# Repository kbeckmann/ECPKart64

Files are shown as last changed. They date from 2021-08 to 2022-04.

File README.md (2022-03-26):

# ECPKart64

A Lattice ECP5 based FPGA Flash Cart for the Nintendo 64

## Build and load over serial

```

# First install FPGA toolchain and LiteX

# Build and load stuff
make bitstream
make load_bitstream
make load_app

# Manually write "reboot" in the terminal, in order to trigger the upload of the app

# Upload a ROM
python -m gateware.ecpkart64.uploader2 --port /dev/ttyUSB1 --csr-csv csr.csv --cic --file myrom.z64

# Turn on power on the N64

```

## SD-Card

Currently this doesn't work properly for some reason (sd-card driver does not manage to interact with the card properly). But these are the steps normally taken:

```
# Build
make bitstream
make app

# Format and mount an SD-Card with FAT
sudo mkfs.vfat -F32 /dev/...
sudo mount /dev/... /mnt/usb

# Mount it and copy files to it
cp build/kilsyth/software/app/app.bin /mnt/usb/
cp rom.z64 /mnt/usb/

# Create boot.json with your configuration
echo '{
	"rom.z64":	0x40000000,
	"app.bin":	0x20000000
}' > /mnt/usb/boot.json

# Unmount, insert and boot. Turn on N64.

```

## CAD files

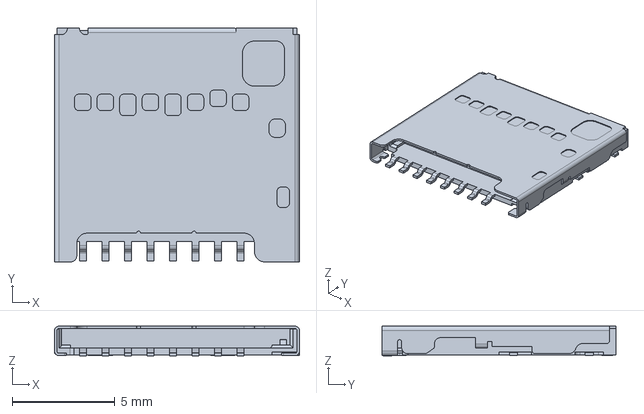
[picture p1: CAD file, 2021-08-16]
hw/3d/1040310811.stp
11.9 x 11.4 x 1.45 mm

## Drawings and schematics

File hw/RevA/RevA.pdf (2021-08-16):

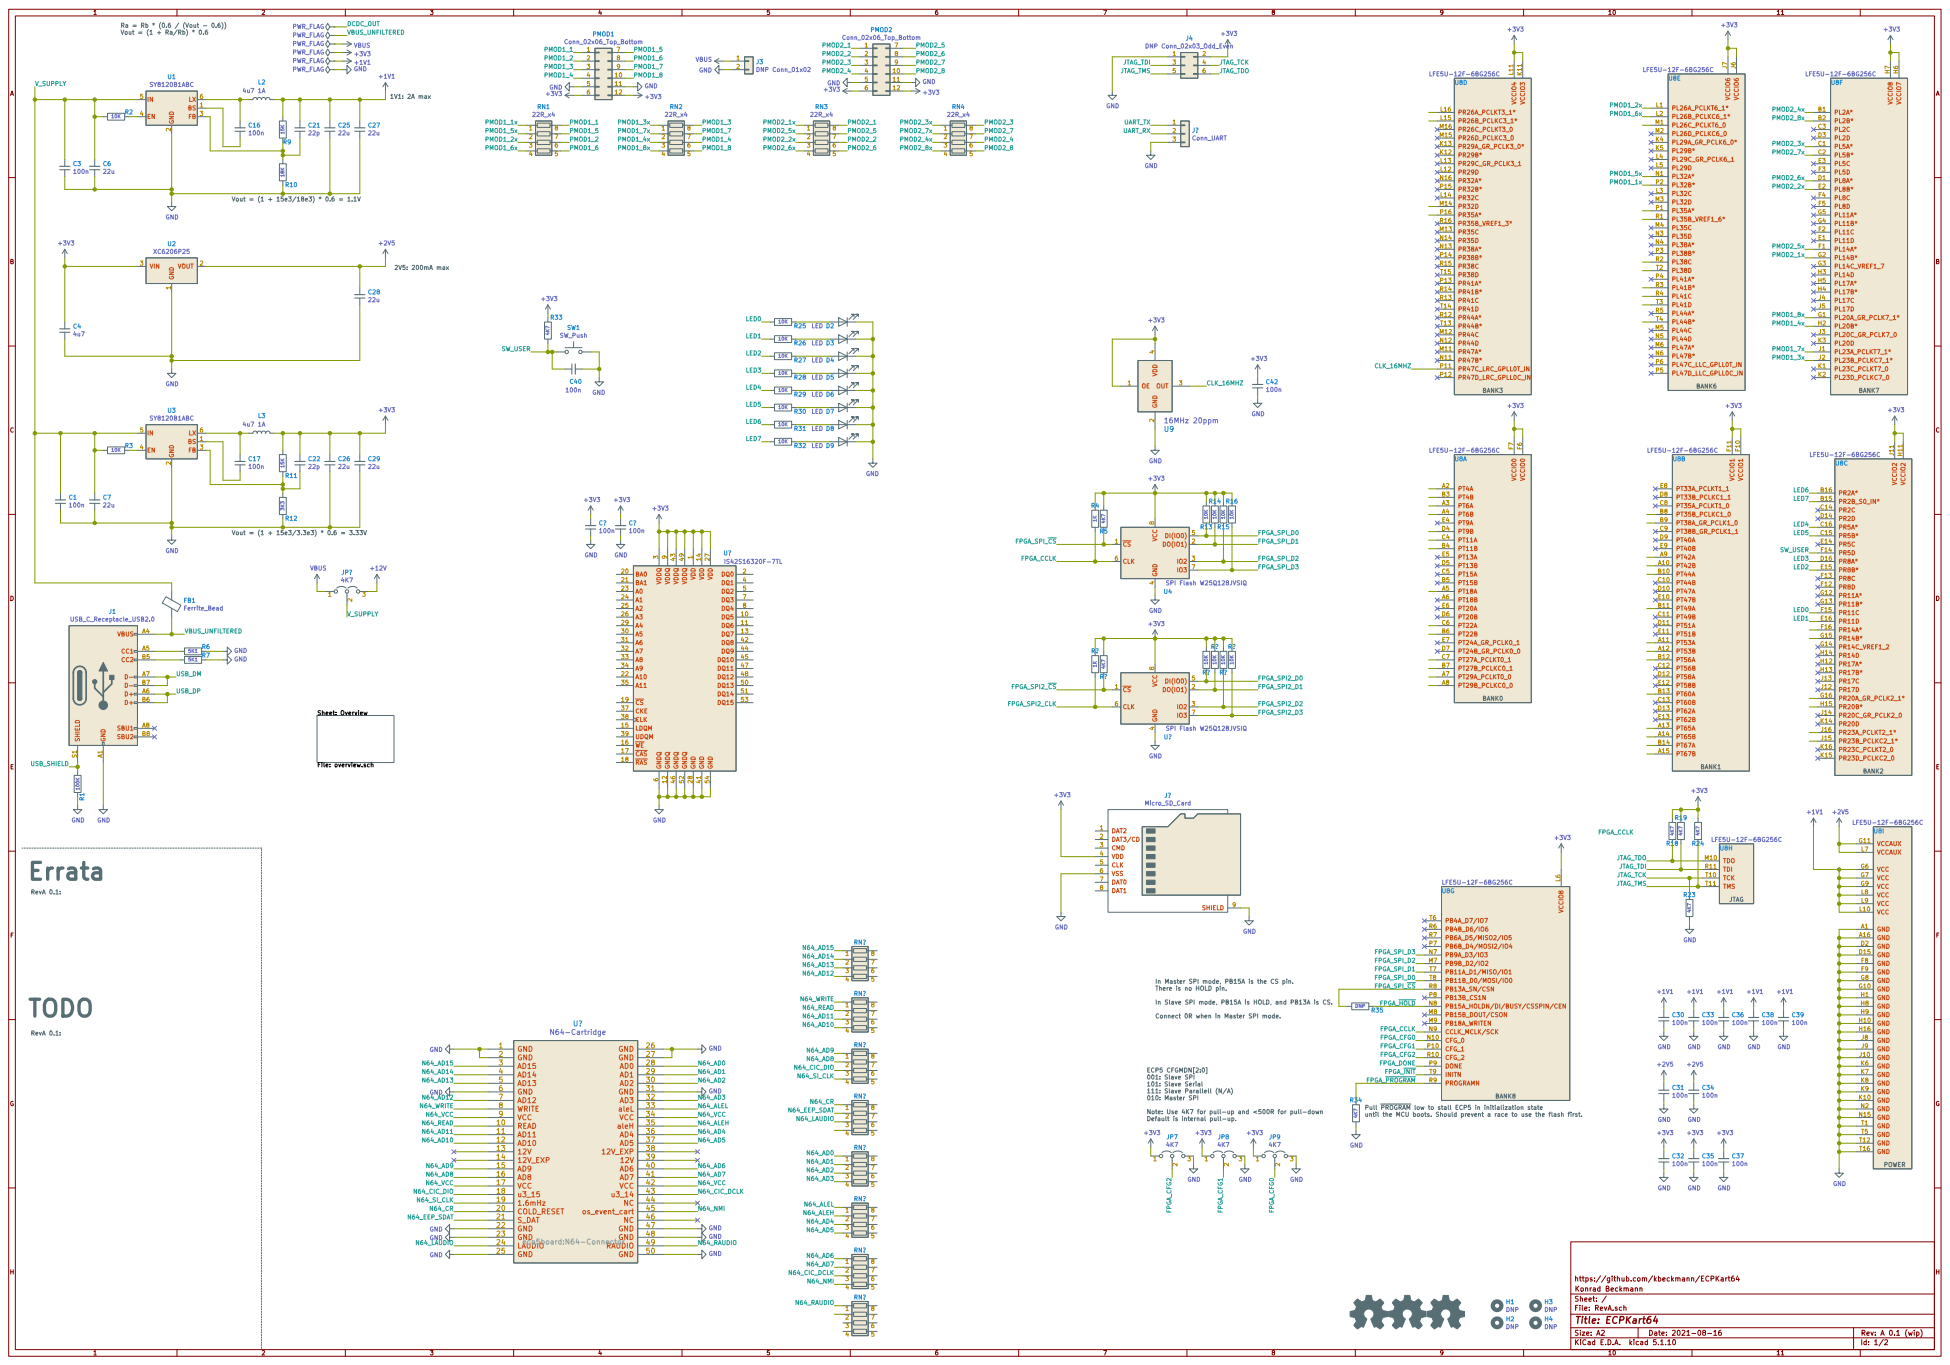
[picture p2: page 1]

3 A5 30 A6 31 A7 32 A8 33 A9 34 A11 35 CKE 37 CLK 38 UDQM 39 DQ1 4 GND 41 DQ8 42 VDDQ 43 DQ9 44 DQ10 45 GNDQ 46 DQ11 47 DQ12 48 VDDQ 49 DQ2 5 DQ13 50 DQ14 51 GNDQ 52 DQ15 53 GND 54 GNDQ

until the MCU boots. Should prevent a race to use the flash first. RevA 0.1:

In Master SPI mode, PB15A is the CS pin.
There is no HOLD pin.

ECP5 CFGMDN[2:0] 001: Slave SPI 101: Slave Serial 111: Slave Parallell (N/A) 010: Master SPI Note: Use 4K7 for pull-up and <500R for pull-down

Default is internal pull-up.

https://github.com/kbeckmann/ECPKart64
File: RevA.sch Sheet: / Konrad Beckmann

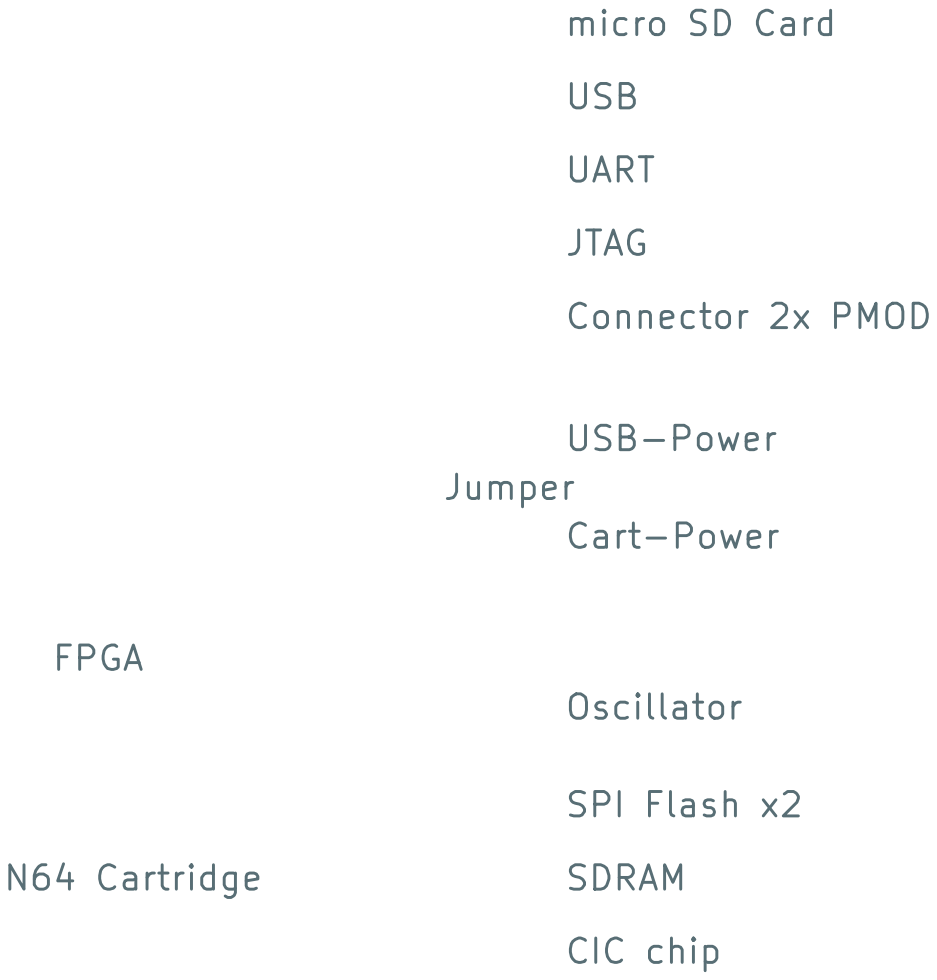
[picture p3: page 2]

SPI Flash x2 USB micro SD Card UART

Cart-Power USB-Power Jumper Oscillator Connector 2x PMOD

Id: 2/2 Title: File: overview.sch Sheet: /Overview/

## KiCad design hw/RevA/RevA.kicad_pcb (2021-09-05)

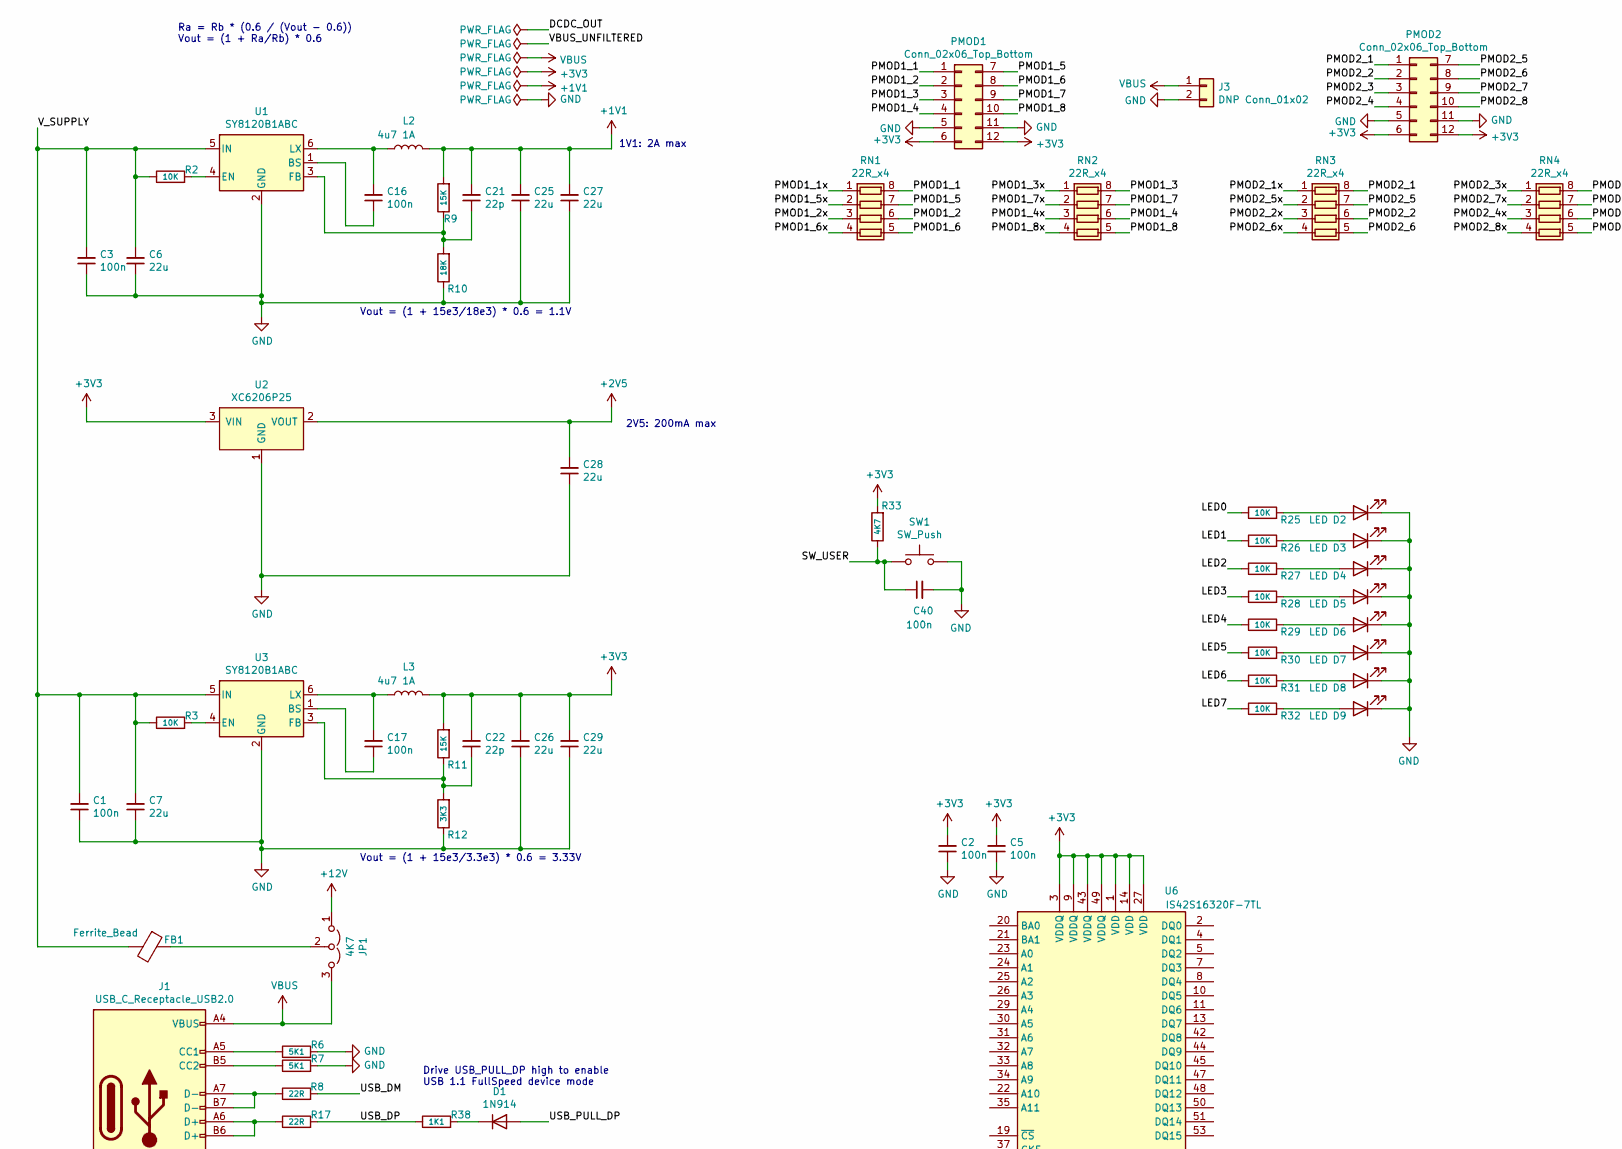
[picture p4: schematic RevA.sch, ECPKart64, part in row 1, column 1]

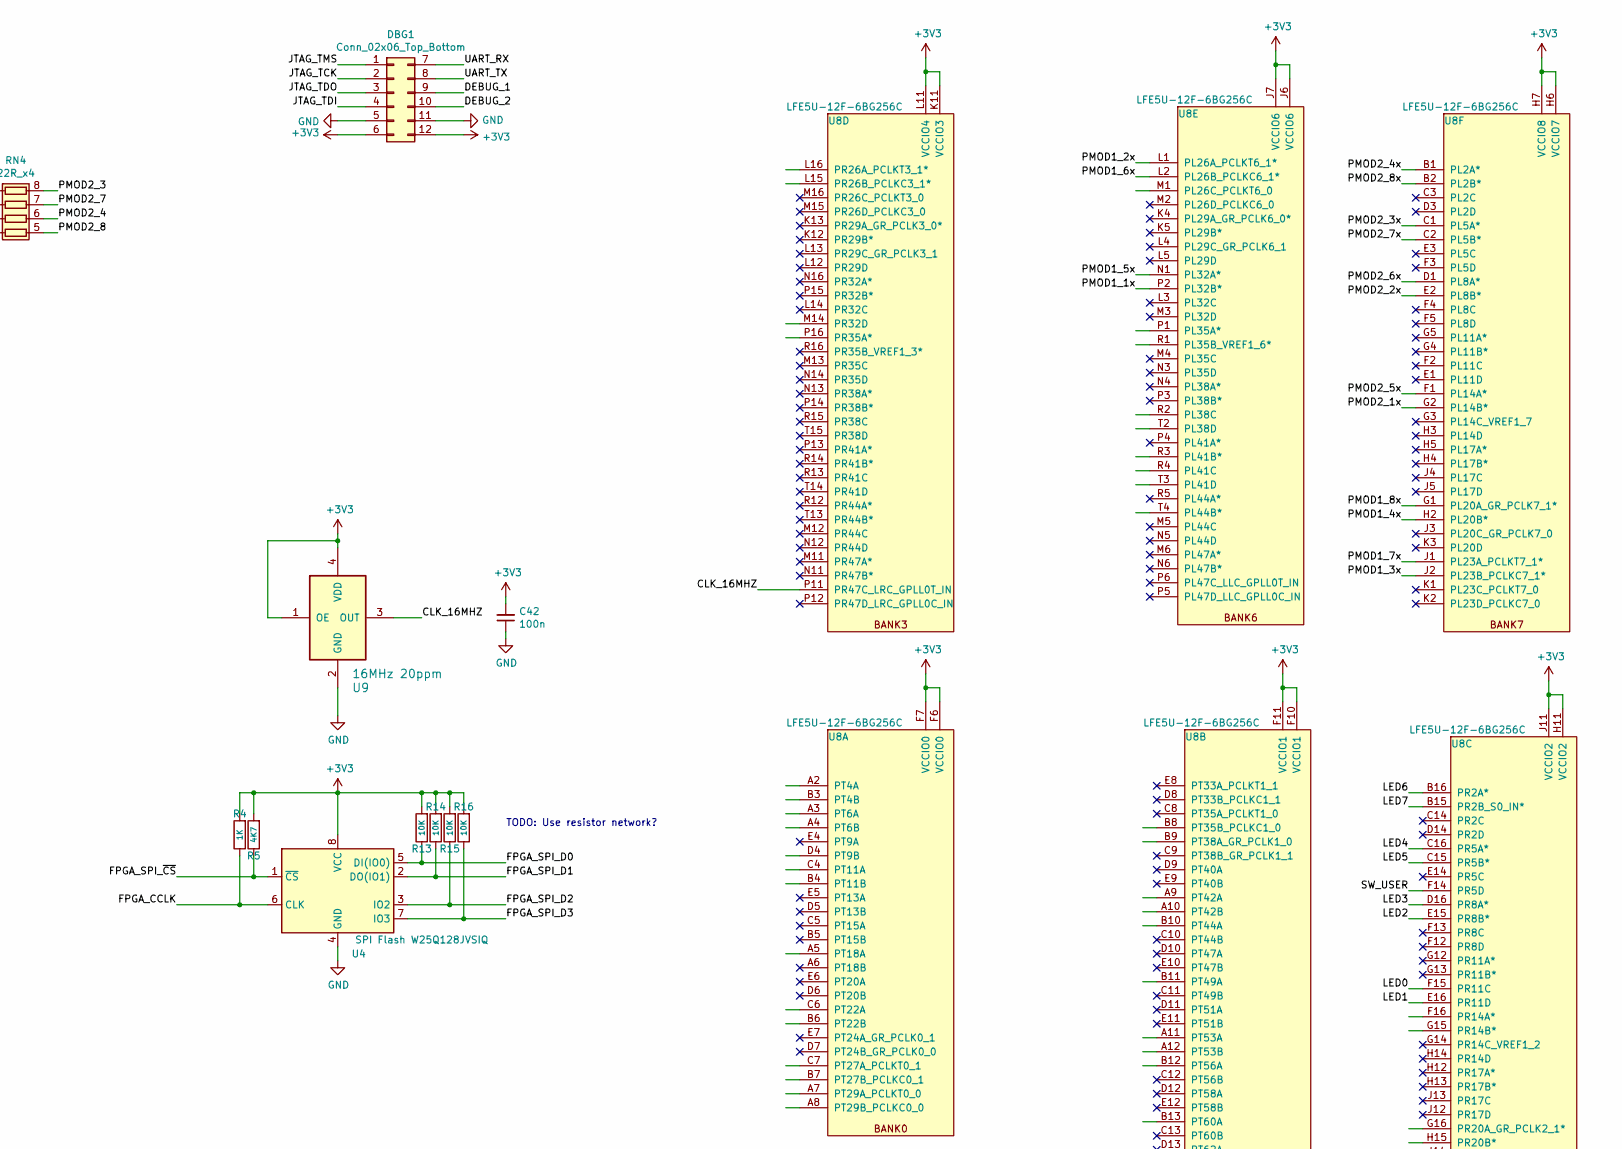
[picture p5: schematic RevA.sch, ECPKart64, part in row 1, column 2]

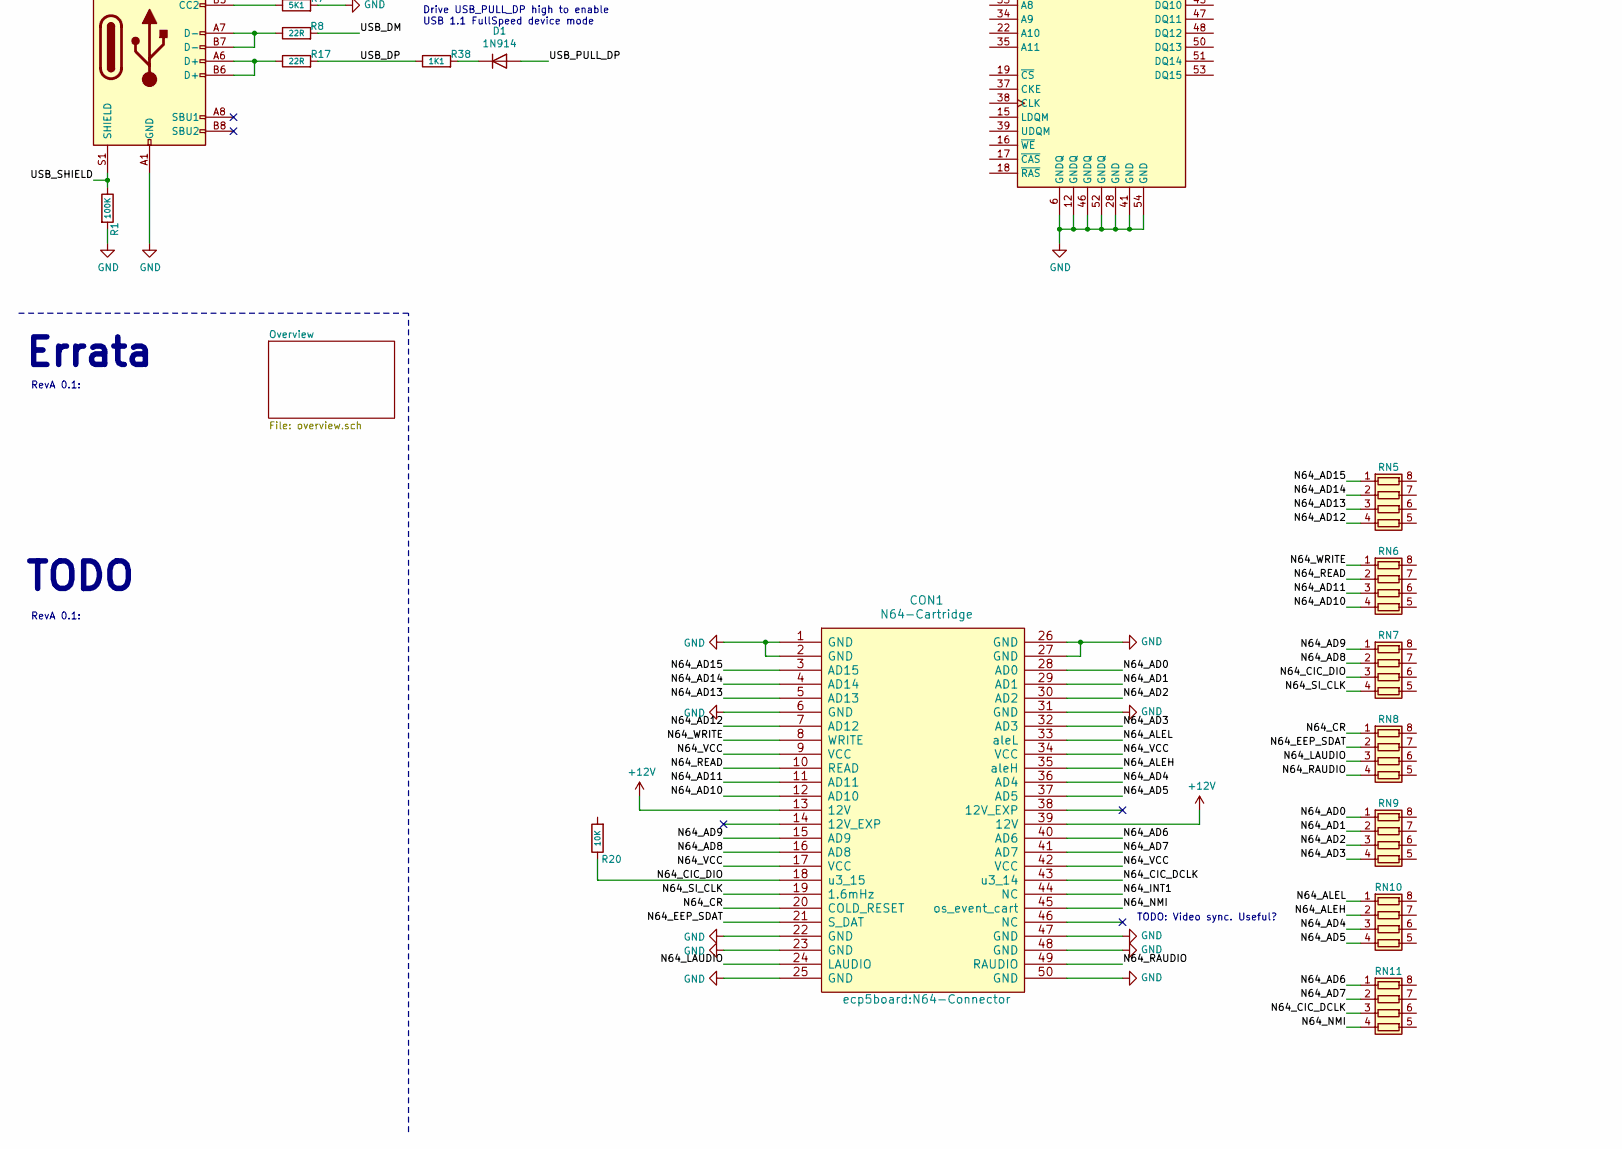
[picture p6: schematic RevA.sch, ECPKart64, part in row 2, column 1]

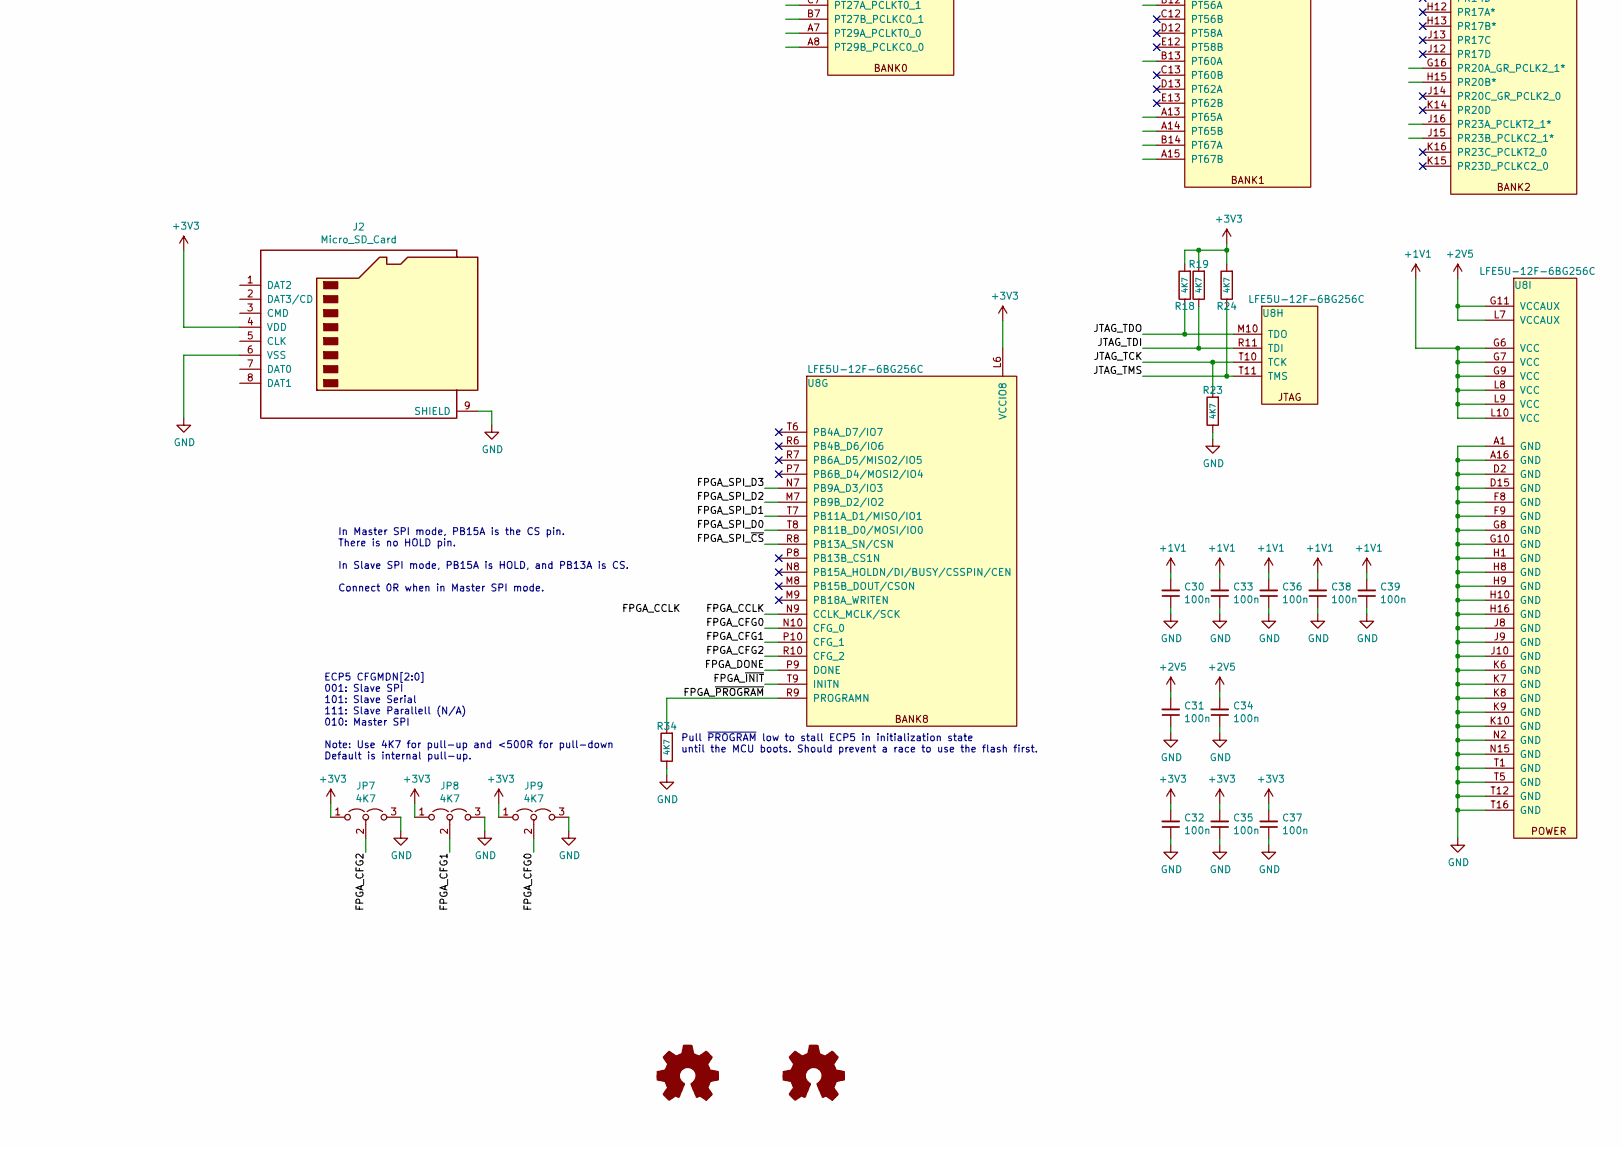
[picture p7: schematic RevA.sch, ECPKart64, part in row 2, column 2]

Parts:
C1, C2, C3, C5, C16, C17, C30, C31, C32, C33, C34, C35, C36, C37, C38, C39, C40, C42: 100n; C_0402_1005Metric
C6, C7, C25, C26, C27, C28, C29: 22u; C_0805_2012Metric; LCSC C98190
C21, C22: 22p; C_0402_1005Metric
CON1: N64-Cartridge; N64-Connector
D1: 1N914; D_SOD-323_HandSoldering
D2, D3, D4, D5, D6, D7, D8, D9: LED; LED_0603_1608Metric; LCSC C84263
DBG1: Conn_02x06_Top_Bottom; PMOD_Socket_2x06_P2.54mm_Horizontal; LCSC C239357
FB1: Ferrite_Bead; L_0805_2012Metric; LCSC C88993
J1: USB_C_Receptacle_USB2.0; USB_C_Receptacle_GT-USB-7010; LCSC C165948
J2: Micro_SD_Card; microSD_HC_Molex_104031-0811
J3: DNP Conn_01x02; PinSocket_1x02_P2.54mm_Vertical
JP1: 4K7; PinHeader_1x03_P2.54mm_Horizontal; LCSC C105871
JP7, JP8, JP9: 4K7; JP_3_0402_1005Metric; LCSC C105871
L2, L3: 4u7 1A; L_1008_1210; LCSC C90319
LOGO1: Logo_Open_Hardware_Small; OSHW-Logo_5.7x6mm_SilkScreen
LOGO3: Logo_Open_Hardware_Small; xil_logo_new
PMOD1, PMOD2: Conn_02x06_Top_Bottom; PMOD_Socket_2x06_P2.54mm_Horizontal; LCSC C239357
R1: 100K; R_0402_1005Metric
R2, R3, R13, R14, R15, R16, R20, R25, R26, R27, R28, R29, R30, R31, R32: 10K; R_0402_1005Metric
R4: 1K; R_0402_1005Metric
R5, R18, R19, R23, R24, R33, R34: 4K7; R_0402_1005Metric
R6, R7: 5K1; R_0402_1005Metric
R8, R17: 22R; R_0402_1005Metric
R9, R11: 15K; R_0402_1005Metric
R10: 18K; R_0402_1005Metric
R12: 3K3; R_0402_1005Metric
R38: 1K1; R_0402_1005Metric
RN1, RN2, RN3, RN4, RN5, RN6, RN7, RN8, RN9, RN10, RN11: 22R_x4; R_Array_Convex_4x0603; LCSC C309446
SW1: SW_Push; SW_SPST_FSMSM; LCSC C118141
U1, U3: SY8120B1ABC; SOT-23-6; LCSC C88474
U2: XC6206P25; SOT-23; LCSC C15906
U4: SPI Flash W25Q128JVSIQ; SOA008-150-208mil; LCSC C97521
U6: IS42S16320F-7TL; TSOP-II-54_22.2x10.16mm_P0.8mm
U8: LFE5U-12F-6BG256C; cabga256; Mouser 842-LFE5U12F6BG256C
U9: 16MHz 20ppm; Crystal_SMD_3225-4Pin_3.2x2.5mm; LCSC C387369

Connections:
+1V1: C21.2, C25.2, C27.2, C30.2, C33.2, C36.2, C38.2, C39.2, L2.2, R9.2, U8.G6 (VCC), U8.G7 (VCC), U8.G9 (VCC), U8.L8 (VCC), U8.L9 (VCC), U8.L10 (VCC)
+2V5: C28.2, C31.2, C34.2, U2.2 (VOUT), U8.G11 (VCCAUX), U8.L7 (VCCAUX)
+3V3: C2.2, C5.2, C22.2, C26.2, C29.2, C32.2, C35.2, C37.2, C42.2, DBG1.6, DBG1.12, J2.4 (VDD), JP7.1 (A), JP8.1 (A), JP9.1 (A), L3.2, PMOD1.6, PMOD1.12, PMOD2.6, PMOD2.12, R4.2, R5.2, R11.2, R13.2, R14.2, R15.2, R16.2, R18.2, R19.2, R24.2, R33.2, U2.3 (VIN), U4.8 (VCC), U6.1 (VDD), U6.3 (VDDQ), U6.9 (VDDQ), U6.14 (VDD), U6.27 (VDD), U6.43 (VDDQ), U6.49 (VDDQ), U8.F6 (VCCIO0), U8.F7 (VCCIO0), U8.F10 (VCCIO1), U8.F11 (VCCIO1), U8.H6 (VCCIO7), U8.H7 (VCCIO8), U8.H11 (VCCIO2), U8.J6 (VCCIO6), U8.J7 (VCCIO6), U8.J11 (VCCIO2), U8.K11 (VCCIO3), U8.L6 (VCCIO8), U8.L11 (VCCIO4), U9.1 (OE), U9.4 (VDD)
+12V: CON1.13 (12V), CON1.39 (12V), JP1.1 (A)
/CLK_16MHZ: U8.P11 (PR47C_LRC_GPLL0T_IN), U9.3 (OUT)
/DEBUG_1: DBG1.9
/DEBUG_2: DBG1.10
/FPGA_CCLK: R4.1, U4.6 (CLK), U8.N9 (CCLK_MCLK/SCK)
/FPGA_CFG0: JP9.2 (C), U8.N10 (CFG_0)
/FPGA_CFG1: JP8.2 (C), U8.P10 (CFG_1)
/FPGA_CFG2: JP7.2 (C), U8.R10 (CFG_2)
/FPGA_DONE: U8.P9 (DONE)
/FPGA_SPI_D0: R13.1, U4.5 (DI(IO0)), U8.T8 (PB11B_D0/MOSI/IO0)
/FPGA_SPI_D1: R14.1, U4.2 (DO(IO1)), U8.T7 (PB11A_D1/MISO/IO1)
/FPGA_SPI_D2: R15.1, U4.3 (IO2), U8.M7 (PB9B_D2/IO2)
/FPGA_SPI_D3: R16.1, U4.7 (IO3), U8.N7 (PB9A_D3/IO3)
/FPGA_SPI_~CS~: R5.1, U4.1 (~CS), U8.R8 (PB13A_SN/CSN)
/FPGA_~INIT: U8.T9 (INITN)
/FPGA_~PROGRAM: R34.2, U8.R9 (PROGRAMN)
/JTAG_TCK: DBG1.2, R23.2, U8.T10 (TCK)
/JTAG_TDI: DBG1.4, R19.1, U8.R11 (TDI)
/JTAG_TDO: DBG1.3, R18.1, U8.M10 (TDO)
/JTAG_TMS: DBG1.1, R24.1, U8.T11 (TMS)
/LED0: R25.1, U8.F15 (PR11C)
/LED1: R26.1, U8.E16 (PR11D)
/LED2: R27.1, U8.E15 (PR8B*)
/LED3: R28.1, U8.D16 (PR8A*)
/LED4: R29.1, U8.C16 (PR5A*)
/LED5: R30.1, U8.C15 (PR5B*)
/LED6: R31.1, U8.B16 (PR2A*)
/LED7: R32.1, U8.B15 (PR2B_S0_IN*)
/N64_AD0: CON1.28 (AD0), RN9.1 (R1.1)
/N64_AD1: CON1.29 (AD1), RN9.2 (R2.1)
/N64_AD2: CON1.30 (AD2), RN9.3 (R3.1)
/N64_AD3: CON1.32 (AD3), RN9.4 (R4.1)
/N64_AD4: CON1.36 (AD4), RN10.3 (R3.1)
/N64_AD5: CON1.37 (AD5), RN10.4 (R4.1)
/N64_AD6: CON1.40 (AD6), RN11.1 (R1.1)
/N64_AD7: CON1.41 (AD7), RN11.2 (R2.1)
/N64_AD8: CON1.16 (AD8), RN7.2 (R2.1)
/N64_AD9: CON1.15 (AD9), RN7.1 (R1.1)
/N64_AD10: CON1.12 (AD10), RN6.4 (R4.1)
/N64_AD11: CON1.11 (AD11), RN6.3 (R3.1)
/N64_AD12: CON1.7 (AD12), RN5.4 (R4.1)
/N64_AD13: CON1.5 (AD13), RN5.3 (R3.1)
/N64_AD14: CON1.4 (AD14), RN5.2 (R2.1)
/N64_AD15: CON1.3 (AD15), RN5.1 (R1.1)
/N64_ALEH: CON1.35 (aleH), RN10.2 (R2.1)
/N64_ALEL: CON1.33 (aleL), RN10.1 (R1.1)
/N64_CIC_DCLK: CON1.43 (u3_14), RN11.3 (R3.1)
/N64_CIC_DIO: CON1.18 (u3_15), R20.1, RN7.3 (R3.1)
/N64_CR: CON1.20 (COLD_RESET), RN8.1 (R1.1)
/N64_EEP_SDAT: CON1.21 (S_DAT), RN8.2 (R2.1)
/N64_INT1: CON1.44 (NC)
/N64_LAUDIO: CON1.24 (LAUDIO), RN8.3 (R3.1)
/N64_NMI: CON1.45 (os_event_cart), RN11.4 (R4.1)
/N64_RAUDIO: CON1.49 (RAUDIO), RN8.4 (R4.1)
/N64_READ: CON1.10 (READ), RN6.2 (R2.1)
/N64_SI_CLK: CON1.19 (1.6mHz), RN7.4 (R4.1)
/N64_VCC: CON1.9 (VCC), CON1.17 (VCC), CON1.34 (VCC), CON1.42 (VCC)
/N64_WRITE: CON1.8 (WRITE), RN6.1 (R1.1)
/PMOD1_1: PMOD1.1, RN1.8 (R1.2)
/PMOD1_1x: RN1.1 (R1.1), U8.P2 (PL32B*)
/PMOD1_2: PMOD1.2, RN1.6 (R3.2)
/PMOD1_2x: RN1.3 (R3.1), U8.L1 (PL26A_PCLKT6_1*)
/PMOD1_3: PMOD1.3, RN2.8 (R1.2)
/PMOD1_3x: RN2.1 (R1.1), U8.J2 (PL23B_PCLKC7_1*)
/PMOD1_4: PMOD1.4, RN2.6 (R3.2)
/PMOD1_4x: RN2.3 (R3.1), U8.H2 (PL20B*)
/PMOD1_5: PMOD1.7, RN1.7 (R2.2)
/PMOD1_5x: RN1.2 (R2.1), U8.N1 (PL32A*)
/PMOD1_6: PMOD1.8, RN1.5 (R4.2)
/PMOD1_6x: RN1.4 (R4.1), U8.L2 (PL26B_PCLKC6_1*)
/PMOD1_7: PMOD1.9, RN2.7 (R2.2)
/PMOD1_7x: RN2.2 (R2.1), U8.J1 (PL23A_PCLKT7_1*)
/PMOD1_8: PMOD1.10, RN2.5 (R4.2)
/PMOD1_8x: RN2.4 (R4.1), U8.G1 (PL20A_GR_PCLK7_1*)
/PMOD2_1: PMOD2.1, RN3.8 (R1.2)
/PMOD2_1x: RN3.1 (R1.1), U8.G2 (PL14B*)
/PMOD2_2: PMOD2.2, RN3.6 (R3.2)
/PMOD2_2x: RN3.3 (R3.1), U8.E2 (PL8B*)
/PMOD2_3: PMOD2.3, RN4.8 (R1.2)
/PMOD2_3x: RN4.1 (R1.1), U8.C1 (PL5A*)
/PMOD2_4: PMOD2.4, RN4.6 (R3.2)
/PMOD2_4x: RN4.3 (R3.1), U8.B1 (PL2A*)
/PMOD2_5: PMOD2.7, RN3.7 (R2.2)
/PMOD2_5x: RN3.2 (R2.1), U8.F1 (PL14A*)
/PMOD2_6: PMOD2.8, RN3.5 (R4.2)
/PMOD2_6x: RN3.4 (R4.1), U8.D1 (PL8A*)
/PMOD2_7: PMOD2.9, RN4.7 (R2.2)
/PMOD2_7x: RN4.2 (R2.1), U8.C2 (PL5B*)
/PMOD2_8: PMOD2.10, RN4.5 (R4.2)
/PMOD2_8x: RN4.4 (R4.1), U8.B2 (PL2B*)
/SW_USER: C40.1, R33.1, SW1.1, U8.F14 (PR5D)
/UART_RX: DBG1.7
/UART_TX: DBG1.8
/USB_DM: R8.2
/USB_DP: R17.2, R38.1
/USB_PULL_DP: D1.2 (A)
/USB_SHIELD: J1.S1 (SHIELD), R1.1
/V_SUPPLY: C1.2, C3.2, C6.2, C7.2, FB1.2, R2.1, R3.1, U1.5 (IN), U3.5 (IN)
GND: C1.1, C2.1, C3.1, C5.1, C6.1, C7.1, C25.1, C26.1, C27.1, C28.1, C29.1, C30.1, C31.1, C32.1, C33.1, C34.1, C35.1, C36.1, C37.1, C38.1, C39.1, C40.2, C42.1, CON1.1 (GND), CON1.2 (GND), CON1.6 (GND), CON1.22 (GND), CON1.23 (GND), CON1.25 (GND), CON1.26 (GND), CON1.27 (GND), CON1.31 (GND), CON1.47 (GND), CON1.48 (GND), CON1.50 (GND), D2.1 (K), D3.1 (K), D4.1 (K), D5.1 (K), D6.1 (K), D7.1 (K), D8.1 (K), D9.1 (K), DBG1.5, DBG1.11, J1.A1 (GND), J1.A12 (GND), J1.B1 (GND), J1.B12 (GND), J2.6 (VSS), J2.9 (SHIELD), J3.2, JP7.3 (B), JP8.3 (B), JP9.3 (B), PMOD1.5, PMOD1.11, PMOD2.5, PMOD2.11, R1.2, R6.2, R7.2, R10.1, R12.1, R23.1, R34.1, SW1.2, U1.2 (GND), U2.1 (GND), U3.2 (GND), U4.4 (GND), U6.6 (GNDQ), U6.12 (GNDQ), U6.28 (GND), U6.41 (GND), U6.46 (GNDQ), U6.52 (GNDQ), U6.54 (GND), U8.A1 (GND), U8.A16 (GND), U8.D2 (GND), U8.D15 (GND), U8.F8 (GND), U8.F9 (GND), U8.G8 (GND), U8.G10 (GND), U8.H1 (GND), U8.H8 (GND), U8.H9 (GND), U8.H10 (GND), U8.H16 (GND), U8.J8 (GND), U8.J9 (GND), U8.J10 (GND), U8.K6 (GND), U8.K7 (GND), U8.K8 (GND), U8.K9 (GND), U8.K10 (GND), U8.N2 (GND), U8.N15 (GND), U8.T1 (GND), U8.T5 (GND), U8.T12 (GND), U8.T16 (GND), U9.2 (GND)
unnamed: C16.1, U1.1 (BS)
unnamed: C16.2, L2.1, U1.6 (LX)
unnamed: C17.1, U3.1 (BS)
unnamed: C17.2, L3.1, U3.6 (LX)
unnamed: C21.1, R9.1, R10.2, U1.3 (FB)
unnamed: C22.1, R11.1, R12.2, U3.3 (FB)
unnamed: D1.1 (K), R38.2
unnamed: D2.2 (A), R25.2
unnamed: D3.2 (A), R26.2
unnamed: D4.2 (A), R27.2
unnamed: D5.2 (A), R28.2
unnamed: D6.2 (A), R29.2
unnamed: D7.2 (A), R30.2
unnamed: D8.2 (A), R31.2
unnamed: D9.2 (A), R32.2
unnamed: FB1.1, JP1.2 (C)
unnamed: J1.A5 (CC1), R6.1
unnamed: J1.A6 (D+), J1.B6 (D+), R17.1
unnamed: J1.A7 (D-), J1.B7 (D-), R8.1
unnamed: J1.B5 (CC2), R7.1
unnamed: R2.2, U1.4 (EN)
unnamed: R3.2, U3.4 (EN)
VBUS: J1.A4 (VBUS), J1.A9 (VBUS), J1.B4 (VBUS), J1.B9 (VBUS), J3.1, JP1.3 (B)

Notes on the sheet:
Ra = Rb * (0.6 / (Vout - 0.6)) Vout = (1 + Ra/Rb) * 0.6
Vout = (1 + 15e3/18e3) * 0.6 = 1.1V
2V5: 200mA max
1V1: 2A max
Vout = (1 + 15e3/3.3e3) * 0.6 = 3.33V
ECP5 CFGMDN[2:0] 001: Slave SPI 101: Slave Serial 111: Slave Parallell (N/A) 010: Master SPI Note: Use 4K7 for pull-up and <500R for pull-down Default is internal pull-up.
Pull ~PROGRAM~ low to stall ECP5 in initialization state until the MCU boots. Should prevent a race to use the flash first.
In Master SPI mode, PB15A is the CS pin. There is no HOLD pin. In Slave SPI mode, PB15A is HOLD, and PB13A is CS. Connect 0R when in Master SPI mode.
Errata
RevA 0.1:
TODO
Drive USB_PULL_DP high to enable USB 1.1 FullSpeed device mode
TODO: Video sync. Useful?
TODO: Use resistor network?

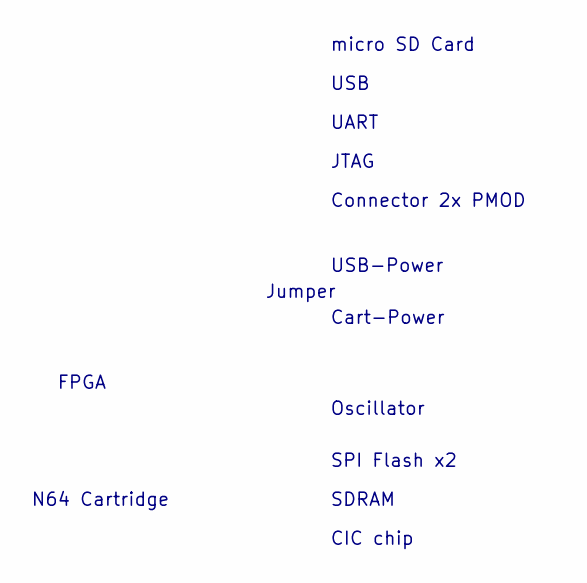
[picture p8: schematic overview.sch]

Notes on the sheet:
N64 Cartridge
FPGA
SDRAM
SPI Flash x2
USB
micro SD Card
UART
JTAG
Cart-Power
USB-Power
Jumper
Oscillator
Connector 2x PMOD
CIC chip

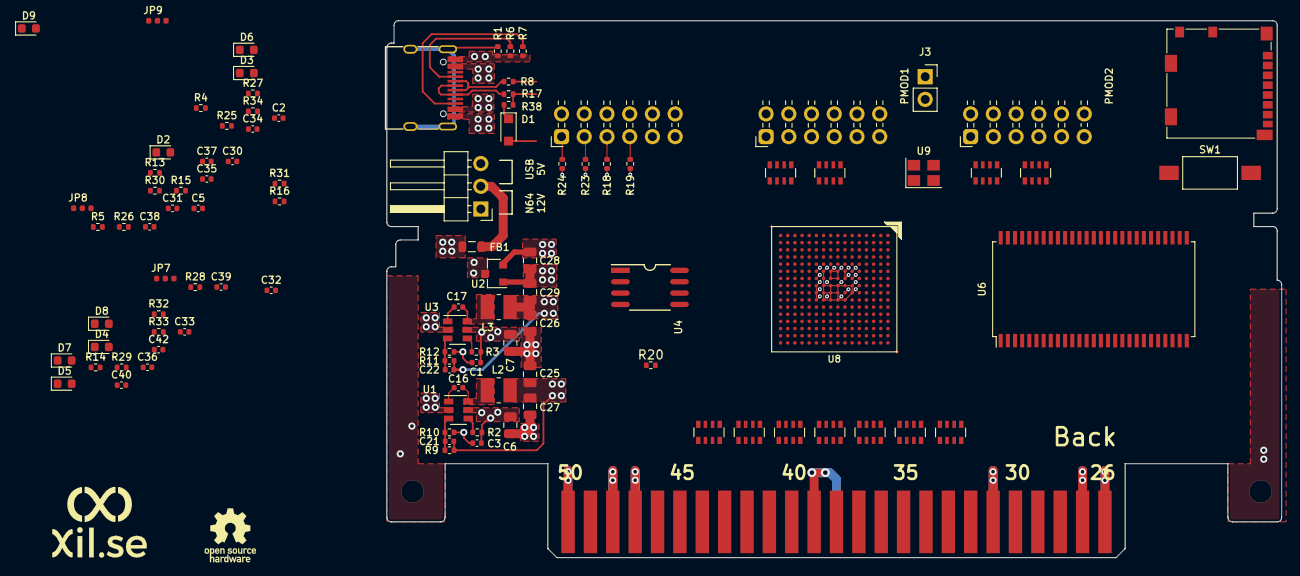
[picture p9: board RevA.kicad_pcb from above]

Board: 4 copper layers, 100.0 x 60.0 mm, 104 parts (1 on the bottom side), 116 nets.

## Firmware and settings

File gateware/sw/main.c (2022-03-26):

// This file is Copyright (c) 2020 Florent Kermarrec <florent@enjoy-digital.fr>
// License: BSD

#include <stdio.h>
#include <stdlib.h>
#include <string.h>

#include <irq.h>
#include <uart.h>
#include <console.h>
#include <generated/csr.h>
#include <generated/mem.h>

#include "sha256.h"
#include "cic.h"

/*-----------------------------------------------------------------------*/
/* Uart                                                                  */
/*-----------------------------------------------------------------------*/

static char *readstr(void)
{
	char c[2];
	static char s[64];
	static int ptr = 0;

	if(readchar_nonblock()) {
		c[0] = readchar();
		c[1] = 0;
		switch(c[0]) {
			case 0x7f:
			case 0x08:
				if(ptr > 0) {
					ptr--;
					putsnonl("\x08 \x08");
				}
				break;
			case 0x07:
				break;
			case '\r':
			case '\n':
				s[ptr] = 0x00;
				putsnonl("\n");
				ptr = 0;
				return s;
			default:
				if(ptr >= (sizeof(s) - 1))
					break;
				putsnonl(c);
				s[ptr] = c[0];
				ptr++;
				break;
		}
	}

	return NULL;
}

static char *get_token(char **str)
{
	char *c, *d;

	c = (char *)strchr(*str, ' ');
	if(c == NULL) {
		d = *str;
		*str = *str+strlen(*str);
		return d;
	}
	*c = 0;
	d = *str;
	*str = c+1;
	return d;
}

static void prompt(void)
{
	printf("\e[92;1mecpkart64-app\e[0m> ");
}

/*-----------------------------------------------------------------------*/
/* Help                                                                  */
/*-----------------------------------------------------------------------*/

static void help(void)
{
	puts("\nECPKart64 app built "__DATE__" "__TIME__"\n");
	puts("Available commands:");
	puts("help               - Show this command");
	puts("reboot             - Reboot CPU");
	puts("cic                - Start CIC emulation");
	puts("");
	puts("mem_read           - Read memory: <address> <length>");
	puts("mem_write          - Write memory: <address> <bytes> <value>");
	puts("mem_load           - Load raw bytes [32b]: <address> <length>");
	puts("mem_dump           - Hexdump [32b]: <address> <length>");
	puts("sha256             - Calculate SHA256 hash of memory: <address> <length>");
	puts("set_header         - Overrides the first word of the rom: <value>");
	puts("");
}

/*-----------------------------------------------------------------------*/
/* Commands                                                              */
/*-----------------------------------------------------------------------*/

static void reboot_cmd(void)
{
	ctrl_reset_write(1);
}

#define NUMBER_OF_BYTES_ON_A_LINE 16
static void dump_bytes(uint32_t *ptr, int count, unsigned long addr)
{
	char *data = (char *)ptr;
	int line_bytes = 0, i = 0;

	putsnonl("Memory dump:");
	while (count > 0) {
		line_bytes =
			(count > NUMBER_OF_BYTES_ON_A_LINE)?
				NUMBER_OF_BYTES_ON_A_LINE : count;

		printf("\n0x%08lx  ", addr);
		for (i = 0; i < line_bytes; i++)
			printf("%02x ", *(unsigned char *)(data+i));

		for (; i < NUMBER_OF_BYTES_ON_A_LINE; i++)
			printf("   ");

		printf(" ");

		for (i = 0; i<line_bytes; i++) {
			if ((*(data+i) < 0x20) || (*(data+i) > 0x7e))
				printf(".");
			else
				printf("%c", *(data+i));
		}

		for (; i < NUMBER_OF_BYTES_ON_A_LINE; i++)
			printf(" ");

		data += (char)line_bytes;
		count -= line_bytes;
		addr += line_bytes;
	}
	printf("\n");
}

static void mem_read(char *address_str, char *len_str)
{
	char *c;
	uint32_t *address = (uint32_t *) strtoul(address_str, &c, 0);
	uint32_t len = strtoul(len_str, &c, 0);

	dump_bytes(address, len, (uint32_t) address);
}

static void mem_write(char *address_str, char *len_str, char *value_str)
{
	char *c;
	uint32_t *address = (uint32_t *) strtoul(address_str, &c, 0);
	uint32_t len = (strtoul(len_str, &c, 0) + 3) / 4;
	uint32_t value = strtoul(value_str, &c, 0);

	for (uint32_t i = 0; i < len; i++) {
		address[i] = value;
	}
}

static void mem_load(char *address_str, char *len_str)
{
	char *c;
	uint32_t *address = (uint32_t *) strtoul(address_str, &c, 0);
	uint32_t words = (strtoul(len_str, &c, 0) + 3) / 4;

	union {
		uint32_t word;
		uint8_t  byte[4];
	} value;

	printf("Reading %ld words\n", words);

	for (int i = 0; i < words; i++) {
		value.byte[0] = readchar();
		value.byte[1] = readchar();
		value.byte[2] = readchar();
		value.byte[3] = readchar();
		address[i] = value.word;
	}
}

static void mem_dump(char *address_str, char *len_str)
{
	char *c;
	union {
		uint32_t word;
		uint8_t  byte[4];
	} value;

	uint32_t *address = (uint32_t *) strtoul(address_str, &c, 0);
	uint32_t len = strtoul(len_str, &c, 0);
	uint32_t written = 0;

	// xxd -p -c 16 < file.hex > file.bin
	for (int i = 0; i < (len + 15) / 16; i++) {
		for (int j = 0; j < 4; j++) {
			value.word = address[i * 4 + j];
			printf("%02x%02x%02x%02x",
				value.byte[0],
				value.byte[1],
				value.byte[2],
				value.byte[3]
			);
			written += 4;
			if (written >= len) {
				printf("\n");
				break;
			}
		}
		printf("\n");
	}
}

static void sha256(char *address_str, char *len_str)
{
	char *c;
	BYTE *address = (BYTE *) strtoul(address_str, &c, 0);
	uint32_t len = strtoul(len_str, &c, 0);
	BYTE hash_str[65];

	sha256_to_string(hash_str, address, len);
	puts((char *) hash_str);
}

static void set_header(char *value_str)
{
	char *c;
	uint32_t value = strtoul(value_str, &c, 0);
	n64_rom_header_write(value);
}

/*-----------------------------------------------------------------------*/
/* Console service / Main                                                */
/*-----------------------------------------------------------------------*/

static void console_service(void)
{
	char *str;
	char *token;

	str = readstr();
	if(str == NULL) return;
	token = get_token(&str);
	if(strcmp(token, "help") == 0)
		help();
	else if(strcmp(token, "reboot") == 0)
		reboot_cmd();
#ifdef CSR_LEDS_BASE
	else if(strcmp(token, "led") == 0)
		led_cmd();
#endif
	else if(strcmp(token, "cic") == 0)
		main_cic();
	else if(strcmp(token, "mem_read") == 0) {
		char *addr = get_token(&str);
		char *len = get_token(&str);
		mem_read(addr, len);
	}
	else if(strcmp(token, "mem_write") == 0) {
		char *addr = get_token(&str);
		char *len = get_token(&str);
		char *value = get_token(&str);
		mem_write(addr, len, value);
	}
	else if(strcmp(token, "mem_load") == 0) {
		char *addr = get_token(&str);
		char *len = get_token(&str);
		mem_load(addr, len);
	}
	else if(strcmp(token, "mem_dump") == 0) {
		char *addr = get_token(&str);
		char *len = get_token(&str);
		mem_dump(addr, len);
	}
	else if(strcmp(token, "sha256") == 0) {
		char *addr = get_token(&str);
		char *len = get_token(&str);
		sha256(addr, len);
	}
	else if(strcmp(token, "set_header") == 0) {
		char *value = get_token(&str);
		set_header(value);
	}
	prompt();
}

int main(void)
{
#ifdef CONFIG_CPU_HAS_INTERRUPT
	irq_setmask(0);
	irq_setie(1);
#endif
	uart_init();

	help();
	prompt();

	// Start CIC automatically (useful when booting from an SDCard)
	printf("cic\n");
	main_cic();

	while(1) {
		console_service();
	}

	return 0;
}

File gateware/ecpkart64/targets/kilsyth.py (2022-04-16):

#!/usr/bin/env python3
#
# This file is part of ECPKart64.
#
# Copyright (c) 2021-2022 Konrad Beckmann <konrad.beckmann@gmail.com>
# SPDX-License-Identifier: BSD-2-Clause

import os
import argparse
import subprocess

from math import log2, ceil

from migen import *

from litex.build.io import DDROutput

from litex.build.lattice.trellis import trellis_args, trellis_argdict

from litex.soc.cores.clock import *
from litex.soc.integration.soc import SoCRegion
from litex.soc.integration.soc_core import *
from litex.soc.integration.builder import *
from litex.soc.interconnect import wishbone
from litex.soc.cores.led import LedChaser
from litex.soc.cores.gpio import GPIOTristate, GPIOIn

from litedram.frontend.wishbone import LiteDRAMWishbone2Native

from litedram.phy import GENSDRPHY, HalfRateGENSDRPHY

from litescope import LiteScopeAnalyzer

# Kind of a hack?
from litedram.modules import SDRAMModule, _TechnologyTimings, _SpeedgradeTimings

from ..platforms import kilsyth

from ..cart import N64Cart


# SDRAM configuration
class K4S561632J_UC75(SDRAMModule):
    memtype = "SDR"
    # geometry
    nbanks = 4
    nrows  = 8192
    ncols  = 512
    # timings
    # technology_timings = _TechnologyTimings(tREFI=64e6/8192, tWTR=(2, None), tCCD=(1, None), tRRD=(None, 15))
    # speedgrade_timings = {"default": _SpeedgradeTimings(tRP=40, tRCD=40, tWR=40, tRFC=(None, 128), tFAW=None, tRAS=100)}

    technology_timings = _TechnologyTimings(tREFI=48e6/8192, tWTR=(2, None), tCCD=(1, None), tRRD=(None, 15))
    speedgrade_timings = {"default": _SpeedgradeTimings(tRP=20, tRCD=20, tWR=15, tRFC=(None, 66), tFAW=None, tRAS=44)}
    # speedgrade_timings = {"default": _SpeedgradeTimings(tRP=10, tRCD=10, tWR=10, tRFC=(None, 65), tFAW=None, tRAS=44)}


# CRG ----------------------------------------------------------------------------------------------

class _CRG(Module):
    def __init__(self, platform, sys_clk_freq, sdram_rate):
        self.rst = Signal()
        self.clock_domains.cd_sys = ClockDomain()
        if sdram_rate == "1:2":
            self.clock_domains.cd_sys2x    = ClockDomain()
            self.clock_domains.cd_sys2x_ps = ClockDomain(reset_less=True)
        else:
            self.clock_domains.cd_sys_ps = ClockDomain(reset_less=True)

        # # #

        # Clk
        clk16 = platform.request("clk16")

        # PLL
        self.submodules.pll = pll = ECP5PLL()
        self.comb += pll.reset.eq(self.rst)
        pll.register_clkin(clk16, 16e6)
        self.clock_domains.cd_usb_48 = ClockDomain()
        pll.create_clkout(self.cd_sys, sys_clk_freq)

        # USB stuff
        if False:
            self.clock_domains.cd_usb_12 = ClockDomain()
            pll.create_clkout(self.cd_usb_12, 12e6, margin=0)
            self.comb += self.cd_usb_48.clk.eq(self.cd_sys.clk)

        if sdram_rate == "1:2":
            pll.create_clkout(self.cd_sys2x,    2 * sys_clk_freq)
            pll.create_clkout(self.cd_sys2x_ps, 2 * sys_clk_freq, phase=180) # Idealy 90° but needs to be increased.
        else:
           pll.create_clkout(self.cd_sys_ps, sys_clk_freq, phase=90)

        # SDRAM clock
        sdram_clk = ClockSignal("sys2x_ps" if sdram_rate == "1:2" else "sys_ps")
        self.specials += DDROutput(1, 0, platform.request("sdram_clock"), sdram_clk)


####

class DualMasterSRAM(Module):
    def __init__(self, mem_or_size, init=None, bus_r=None, bus_w=None):
        self.bus_r = bus_r
        self.bus_w = bus_w
        bus_data_width = len(self.bus_r.dat_r)
        self.mem = Memory(bus_data_width, mem_or_size//(bus_data_width//8), init=init)

        # memory
        port_r = self.mem.get_port(write_capable=False, we_granularity=8, mode=READ_FIRST)
        port_w = self.mem.get_port(write_capable=True, we_granularity=8, mode=WRITE_FIRST)
        self.specials += self.mem, port_r, port_w
        # generate write enable signal
        self.comb += [port_w.we[i].eq(self.bus_w.cyc & self.bus_w.stb & self.bus_w.we & self.bus_w.sel[i])
            for i in range(bus_data_width//8)]
        # address and data
        self.comb += [
            port_r.adr.eq(self.bus_r.adr[:len(port_r.adr)]),
            self.bus_r.dat_r.eq(port_r.dat_r),

            port_w.adr.eq(self.bus_w.adr[:len(port_w.adr)]),
        ]
        self.comb += port_w.dat_w.eq(self.bus_w.dat_w),
        # generate ack
        self.sync += [
            self.bus_w.ack.eq(0),
            If(self.bus_w.cyc & self.bus_w.stb & ~self.bus_w.ack, self.bus_w.ack.eq(1)),

            self.bus_r.ack.eq(0),
            If(self.bus_r.cyc & self.bus_r.stb & ~self.bus_r.ack, self.bus_r.ack.eq(1))
        ]

# BaseSoC ------------------------------------------------------------------------------------------
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

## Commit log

2021-08-16 Fork Pergola
    [RevA.kicad_pcb, RevA.sch]
2021-08-16 Import pcb shape
    [RevA.kicad_pcb]
2021-08-27 Add initial gateware bringup using Kilsyth
    [SiPEED.cfg, kilsyth_lfe5u12.cfg, kilsyth_lfe5u25.cfg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]
2021-08-27 CIC: Add early port (probably broken)
    [cic.c, main.c]
2021-08-30 Fetch from SDRAM (not working properly yet)
    [cic.c, kilsyth.py, main.c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]
2021-09-03 cic: Exit the CIC app on any uart input
2021-09-03 cic: Exit when reset is detected
    [cic.c]
2021-09-03 cic: Improve reset logic
    [cic.c, uploader2.py]
2021-09-05 hw: Progress
    - Added pullup resistor for CIC data
    - Removed extra SPI flash (no need for it anymore)
    - Rounded corners
    [RevA.kicad_pcb, RevA.sch]
2021-09-05 cic: Print less to start faster
2021-09-05 cic: Remove print after reset
    [cic.c]
2022-03-27 Add framebuffer dumper
